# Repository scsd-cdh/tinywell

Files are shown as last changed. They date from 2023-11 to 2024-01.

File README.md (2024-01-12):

# Tinywell - Microfluidic Experiment Platform for Yeast Growth

## Overview
This project presents a microfluidic experiment platform designed to test yeast growth and viability under various LED wavelengths. It allows for simultaneous testing of up to 16 wells, providing an efficient and innovative approach to studying yeast behavior.

## Contents
The repository is organized into four main folders:

### 1. Altium
Contains all the schematics and assembly files for the PCBs (Printed Circuit Boards) used in the project. These files are essential for understanding the electronic design and layout.

### 2. CAD
Holds all CAD (Computer-Aided Design) files, created using NX software. These files represent the physical design and structure of the experimental platform.

### 3. Dashboard
Includes the user interface code, developed in Rust. This folder is crucial for those looking to modify or understand the front-end aspect of the platform.

### 4. Teensyduino
Contains the Teensyduino code responsible for controlling the boards designed in the Altium folder. This is where you'll find the firmware and related software for board operations.

## Getting Started

### Prerequisites
1. Assemble the PCBs designed in the altium folder. This requires some skill as both the LEDs and light sensors were quite small. Our team struggled at first and recommend getting extras for practice.
2. Print the CADs in the provided folder. Our team used PLA.
3. Download the exe provided in the release or build the program in the dashboard folder.
4. Upload the .ino file in the Teensyduino folder onto your Teensyduino.

### Usage
Once everything is assembled, you should be able to run the dashboard, connect your Teensyduino to your computer, design the pattern for the LEDs and run the sequence.
A file with the results will be generated in the folder where the executable is. You may change the file by going to File in the menu bar and clicking "Results Directory".

## License
This project is licensed under the GNU General Public License (GPL). This means that it's free to use and modify, and it ensures that all derivative works are also open-source. The GPL is a widely used free software license, guaranteeing end users the freedom to run, study, share, and modify the software.
For more details, see the GPLv3 license or the LICENSE file included in the repository.

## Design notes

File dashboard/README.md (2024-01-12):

# Tinywell - Dashboard

## Overview
This dashboard is a crucial component of the microfluidic experiment platform designed for testing yeast growth and viability. It provides a user-friendly interface to control and monitor the experiment. Users can select the brightness, change the LED wavelength, choose specific wells, and set the duration for LED sequences.

## Installation
1. Clone the repository.
2. Navigate to the `dashboard` folder.
3. Run `cargo run`.

## License
This project is licensed under the GNU General Public License (GPL). See the GPLv3 license or the LICENSE file in the root directory for more details.

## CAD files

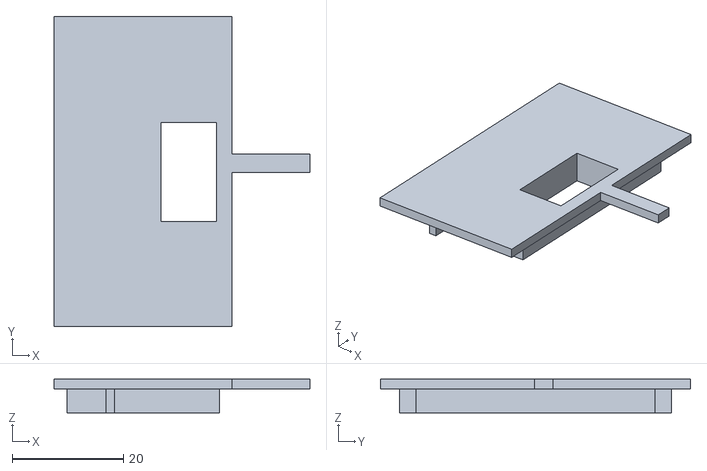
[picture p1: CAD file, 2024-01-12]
cad/SC-FREYR-MGSE-700-0011-ArduinoHousingCap.stl
46.0 x 55.8 x 6.10

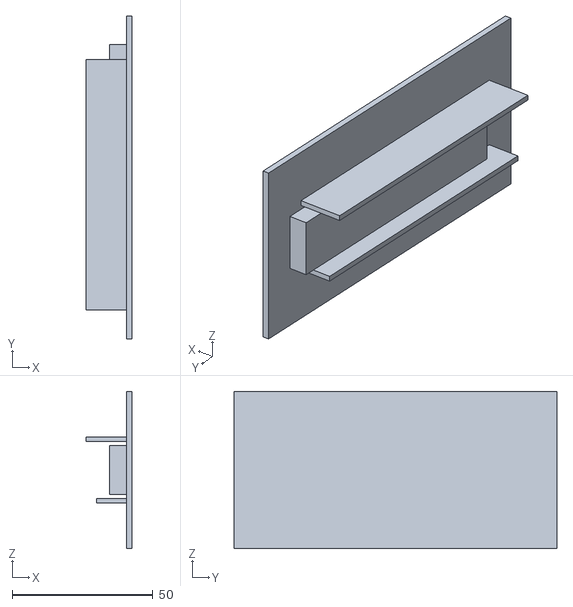
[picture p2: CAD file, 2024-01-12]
cad/SC-FREYR-MGSE-700-0008-Front_Cap.stl
16.3 x 114.5 x 55.8

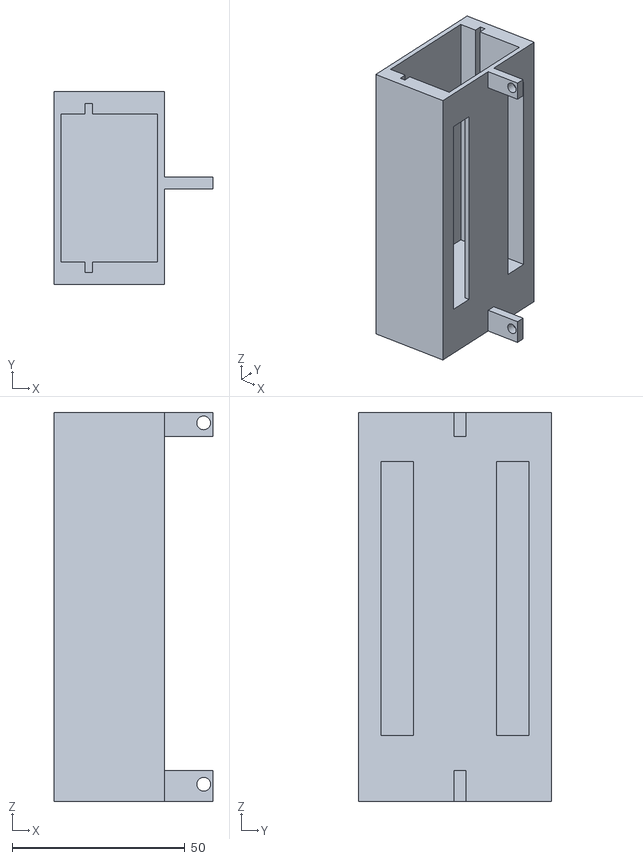
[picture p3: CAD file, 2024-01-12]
cad/SC-FREYR-MGSE-700-0010-ArduinoHousing.stl
46.0 x 55.8 x 112.5

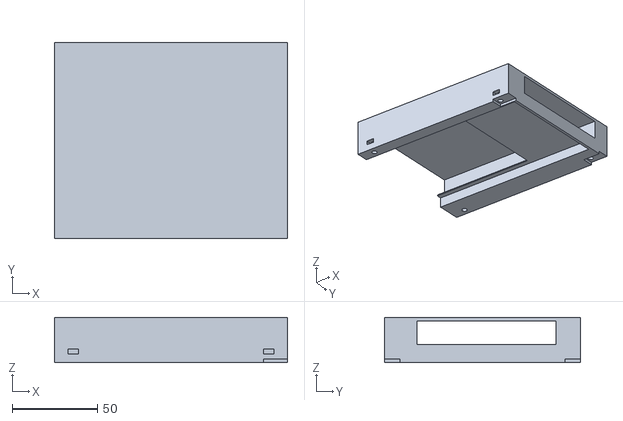
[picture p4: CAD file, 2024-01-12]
cad/SC-FREYR-MGSE-700-0009-TopCap.stl
136.4 x 114.5 x 26.4

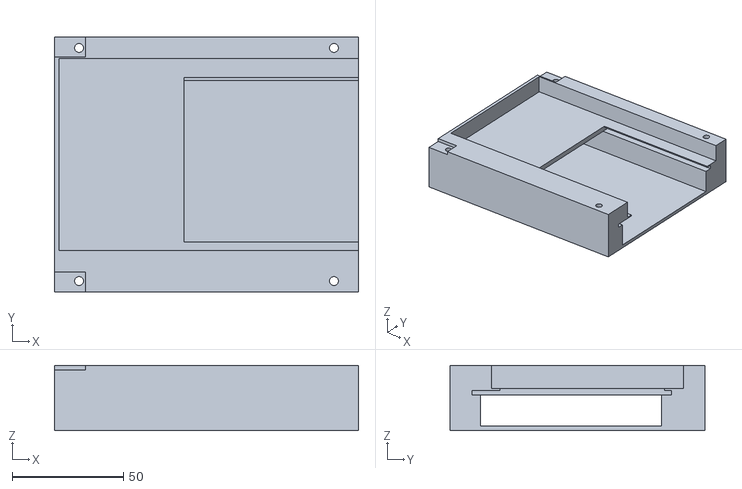
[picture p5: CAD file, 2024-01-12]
cad/SC-FREYR-MGSE-700-0003-BottomCap.stl
136.4 x 114.5 x 29.3

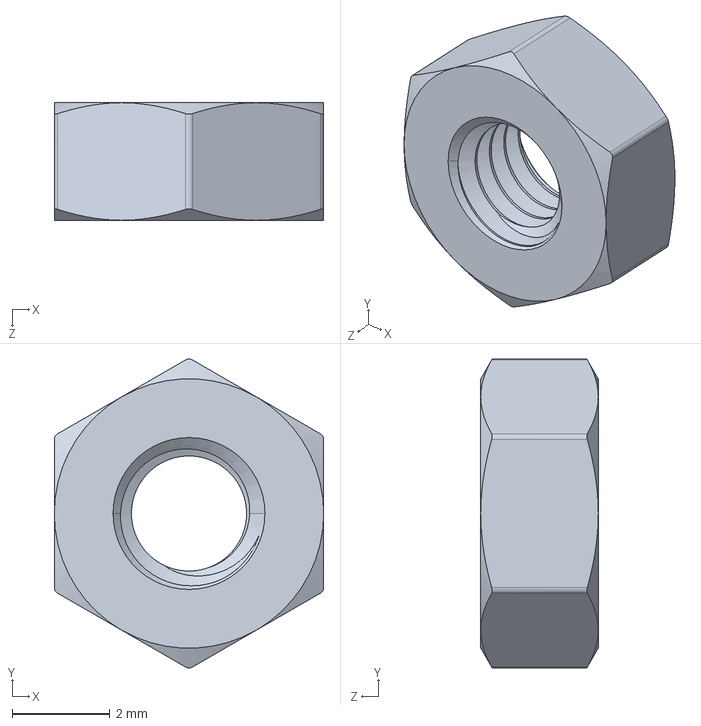
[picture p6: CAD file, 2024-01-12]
cad/m3_nut.STEP
5.50 x 6.31 x 2.40 mm

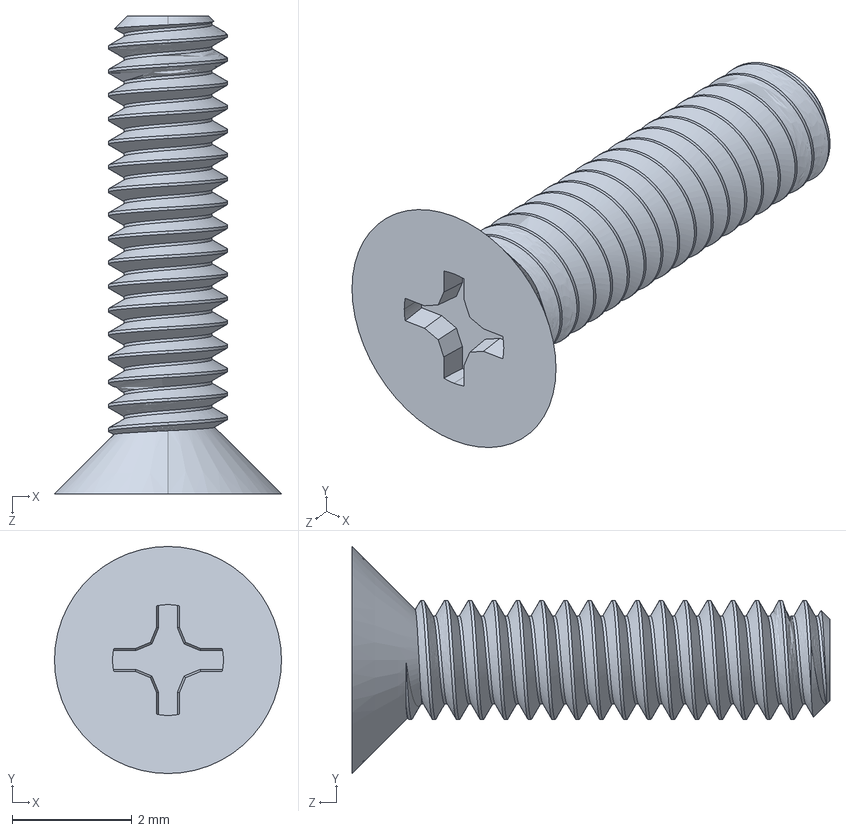
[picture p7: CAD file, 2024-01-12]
cad/m2_screw.STEP
3.80 x 3.80 x 8.00 mm

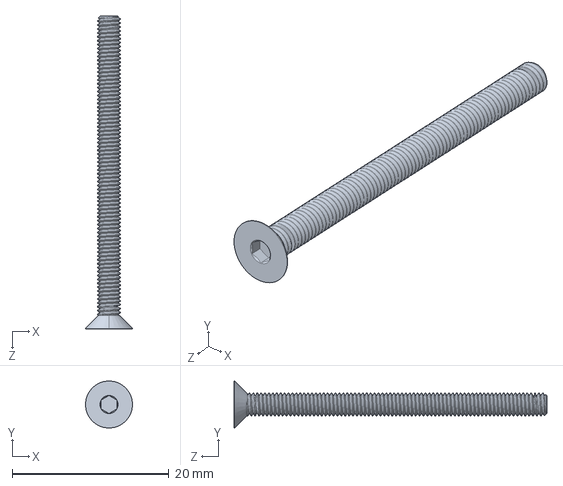
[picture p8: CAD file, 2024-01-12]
cad/m3_screw.STEP
6.00 x 6.00 x 40.0 mm

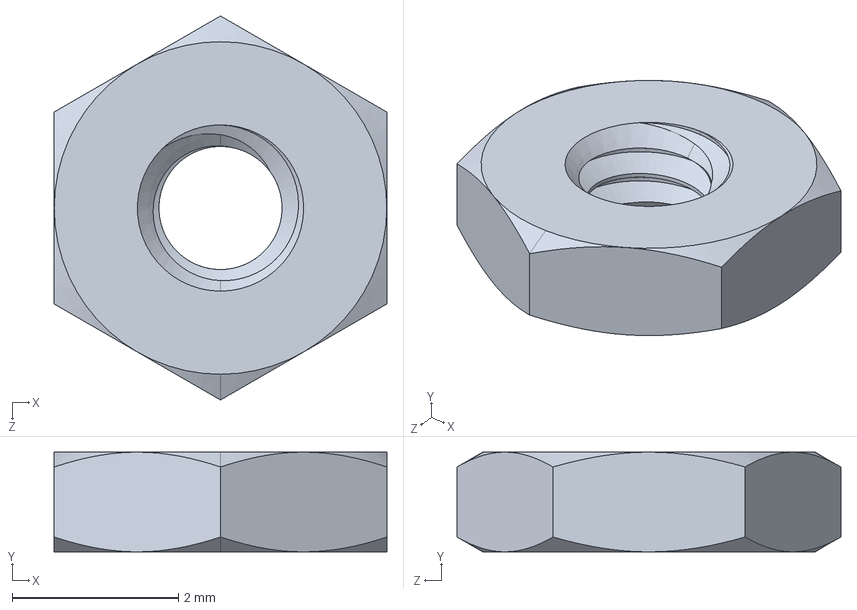
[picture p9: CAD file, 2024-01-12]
cad/m2_nut.STEP
4.00 x 1.20 x 4.62 mm

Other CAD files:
cad/SC-FREYR-MGSE-700-0000-AY_Mechanical_Jig_Assembly.prt
cad/SC-FREYR-MGSE-700-0003-BottomCap.prt
cad/SC-FREYR-MGSE-700-0005-TeensyDuino_PCB_Assembly.prt
cad/SC-FREYR-MGSE-700-0007-96_Well_Plate.prt
cad/SC-FREYR-MGSE-700-0008-Front_Cap.prt
cad/SC-FREYR-MGSE-700-0009-TopCap.prt
cad/SC-FREYR-MGSE-700-0010-ArduinoHousing.prt
cad/SC-FREYR-MGSE-700-0011-ArduinoHousingCap.prt
cad/m2_nut_step.prt
cad/m3_nut_step.prt

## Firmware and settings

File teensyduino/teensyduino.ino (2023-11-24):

#include <Wire.h>

// Make sure these are correct
#define DATA   17
#define CLK    16
#define LATCH  15
#define ENABLE 14

#define MUX_ADDR_1    0x70
#define MUX_ADDR_2    0x77

#define LTR303_ADDR                  0x29
#define LTR303_ALS_CONTR_REG         0x80
#define LTR303_ALS_MEAS_RATE_REG     0x85
#define LTR303_ALS_DATA_CH1_REG      0x88

#define ALS_GAIN  96.0
#define ALS_INT    1.0

uint8_t current_channel = 0;
uint16_t sensor_data = 0;

// Initialize a 64-bit array to keep track of the state of each bit
uint8_t bitArray[8] = {0, 0, 0, 0, 0, 0, 0, 0};

void setup() {
  // Turn LED connected to pin 13 on Teensy to show the board is connected.
  pinMode(13, OUTPUT);
  digitalWrite(13, HIGH);

  // Setup Communication
  Serial.begin(115200);
  Wire.begin();
  
  // Initialize all sensors.
  for(int i = 0; i < 8; i ++) {
    current_channel = pow(2, i);

    set_channel(MUX_ADDR_1, current_channel);
    initialize_sensor();
    set_channel(MUX_ADDR_1, 0);

    delay(250);
    
    set_channel(MUX_ADDR_2, current_channel);
    initialize_sensor();
    set_channel(MUX_ADDR_2, 0);
    
    delay(250);
  }

  // Setup LEDs
  pinMode(LATCH, OUTPUT);
  pinMode(CLK, OUTPUT);
  pinMode(DATA, OUTPUT);
  pinMode(ENABLE, OUTPUT);
}

void loop(){

  for(uint8_t i = 0; i < 8; i ++) {
    current_channel = pow(2, i);

    // FROM MUX 1
    set_channel(MUX_ADDR_1, current_channel);
    
    sensor_data = (uint16_t) read_sensor();
    
    uint8_t low_byte = sensor_data & 0xFF;
    uint8_t high_byte = (sensor_data >> 8) & 0xFF;

    Serial.write(i);
    Serial.write(low_byte);
    Serial.write(high_byte);
    
    set_channel(MUX_ADDR_1, 0);
   
    set_channel(MUX_ADDR_2, current_channel);
    
    sensor_data = (uint16_t) read_sensor();
    
    low_byte = sensor_data & 0xFF;
    high_byte = (sensor_data >> 8) & 0xFF;

    Serial.write(0b10000000 | i);
    Serial.write(low_byte);
    Serial.write(high_byte);
    
    set_channel(MUX_ADDR_2, 0);
  }
  
  while (Serial.available() > 0) {
    uint8_t cmd = Serial.read();
    
    if(cmd == 0b11111111) {
      // Prepare LEDs
      turn_leds_off();
      cmd = Serial.read();
      analogWrite(ENABLE, cmd);
    } else {
      int state = (cmd & 0b10000000) ? HIGH : LOW;
      int bitIndex = cmd & 0b01111111;
      
      setBit(bitIndex, state);
    }
  }

  delay(100);
}

void turn_leds_off() {
  digitalWrite(LATCH, LOW);

  for(int i = 0; i < 8; i ++) {
    bitArray[i] = 0.0;
  }
  
  shiftOut(DATA, CLK, MSBFIRST, 0);
  shiftOut(DATA, CLK, MSBFIRST, 0);

  shiftOut(DATA, CLK, MSBFIRST, 0);
  shiftOut(DATA, CLK, MSBFIRST, 0);

  shiftOut(DATA, CLK, MSBFIRST, 0);
  shiftOut(DATA, CLK, MSBFIRST, 0);

  shiftOut(DATA, CLK, MSBFIRST, 0);
  shiftOut(DATA, CLK, MSBFIRST, 0);
  
  digitalWrite(LATCH, HIGH);
}

void setBit(int bitIndex, int state) {
  if (bitIndex < 0 || bitIndex >= 64) {
    return; // bit index out of bounds
  }

  // Determine which byte and bit within that byte the target bit resides
  int byteIndex = bitIndex / 8;
  int bitPosition = bitIndex % 8;

  // Set or clear the specific bit
  if (state == HIGH) {
    bitSet(bitArray[byteIndex], bitPosition);
  } else {
    bitClear(bitArray[byteIndex], bitPosition);
  }

  // Update the shift register outputs
  updateShiftRegisters();
}

void updateShiftRegisters() {
  digitalWrite(LATCH, LOW);

  // Push each byte to the shift registers, starting from the last one
  for (int i = 0; i < 8; i++) {
    shiftOut(DATA, CLK, MSBFIRST, bitArray[i]);
  }

  digitalWrite(LATCH, HIGH); // Latch the data
}

void set_channel(uint8_t addr, uint8_t channel) {
  Wire.beginTransmission(addr);
  Wire.write(channel);
  Wire.endTransmission();
}

void initialize_sensor() {
  // This will set the gain of the sensor to x96
  Wire.beginTransmission(LTR303_ADDR);
  Wire.write(LTR303_ALS_CONTR_REG);
  Wire.write(0x1D);
  Wire.endTransmission();

  // This will set the integration rate to 50ms and measurement rate to 100ms
  Wire.beginTransmission(LTR303_ADDR);
  Wire.write(LTR303_ALS_MEAS_RATE_REG);
  Wire.write(0x09);
  Wire.endTransmission();
}

float read_sensor() {
  // Set to register to data
  Wire.beginTransmission(LTR303_ADDR);
  Wire.write(LTR303_ALS_DATA_CH1_REG);
  Wire.endTransmission();

  // Read 4 bytes and wait until you have 4 bytes to read
  Wire.requestFrom(LTR303_ADDR, 4);
  while(Wire.available() != 4);

  // Read and print channel 1 and 0
  uint16_t reading_1 = Wire.read();
  reading_1 |= Wire.read() << 8;

  uint16_t reading_0 = Wire.read();
  reading_0 |= Wire.read() << 8;

  float ch0 = (float) reading_0;
  float ch1 = (float) reading_1;
 
  float ratio = ch1/(ch0+ch1);
  if (ratio < 0.45) {
    return (1.7743*ch0 + 1.1059*ch1)/ALS_GAIN/ALS_INT;
  } else if (ratio < 0.64 && ratio >= 0.45) {
    return (4.2785*ch0 - 1.9548*ch1)/ALS_GAIN/ALS_INT;
  } else if (ratio < 0.85 && ratio >= 0.64) {
    return (0.5926*ch0 + 0.1185*ch1)/ALS_GAIN/ALS_INT;
  } else {
    return 0.0;
  }
}

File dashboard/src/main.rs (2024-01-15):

use dashboard::Application;
use eframe::{egui, NativeOptions, Theme};

fn main() -> Result<(), eframe::Error> {
    let options = NativeOptions {
        decorated: true,
        transparent: true,
        follow_system_theme: false,
        default_theme: Theme::Dark,
        min_window_size: Some(egui::vec2(900.0, 720.0)),
        initial_window_size: Some(egui::vec2(900.0, 720.0)),
        resizable: false,
        ..Default::default()
    };
    eframe::run_native(
        "Tinywell",
        options,
        Box::new(|cc| {
            let app = Application::new(cc);
            Box::new(app)
        }),
    )
}

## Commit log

2023-09-06 Basic layout with buttons
2023-09-06 Recording button
2023-09-07 Added arduino code
2023-09-09 Updates to Arduino. Reads sensors on a loop
2023-09-16 Group well states into plates. Allow for sequences of plates
2023-09-16 Simulate sequence of micro plates
2023-09-16 Arduino code updated to have both boards and UI reads from serial port
2023-09-16 Add damaged LEDs
2023-10-28 Dashboard now doesn't follow system theme
    [main.rs]
2023-11-19 Remove damaged LED initialization
    [main.rs, teensyduino.ino]
2023-11-24 Updates to the sensor positions and excel output
2024-01-12 Additional CAD files and altium files
    [Cover_Page.SchDoc, I2C_Protection.SchDoc, Interface.SchDoc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]
2024-01-15 Fix to layout, deselect/select all, better result excel
    [main.rs]
